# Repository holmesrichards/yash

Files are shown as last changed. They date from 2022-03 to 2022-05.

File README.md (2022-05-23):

# YASH

This is a Kosmo format version of René Schmitz's [YASH](https://www.schmitzbits.de/sah.html) sample and hold synth module.

The circuit is pretty much as Schmitz designed it. The only significant changes are the addition of an output jack for the clock signal, an attenuator for the input signal, and a switch to bypass the capacitor on the clock input. The latter turns the module from a sample and hold into a track and hold: applying a gate to the clock input causes the output to track the input voltage, and then when the gate turns off the last output voltage is held until the next gate.

## Current draw
11.3 mA +12 V, 4.0 mA -12 V

## Photos

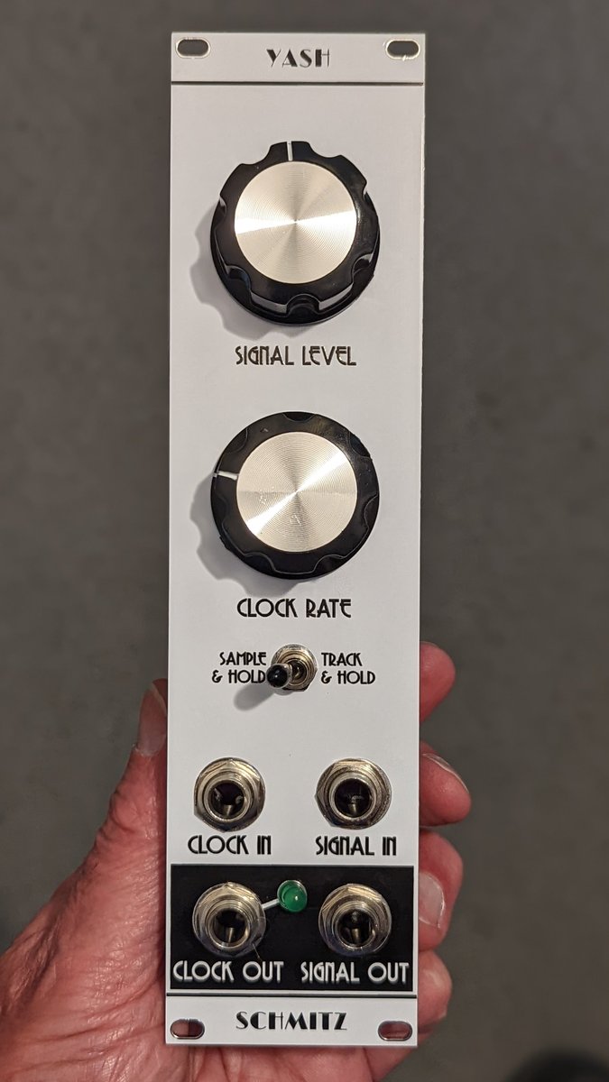
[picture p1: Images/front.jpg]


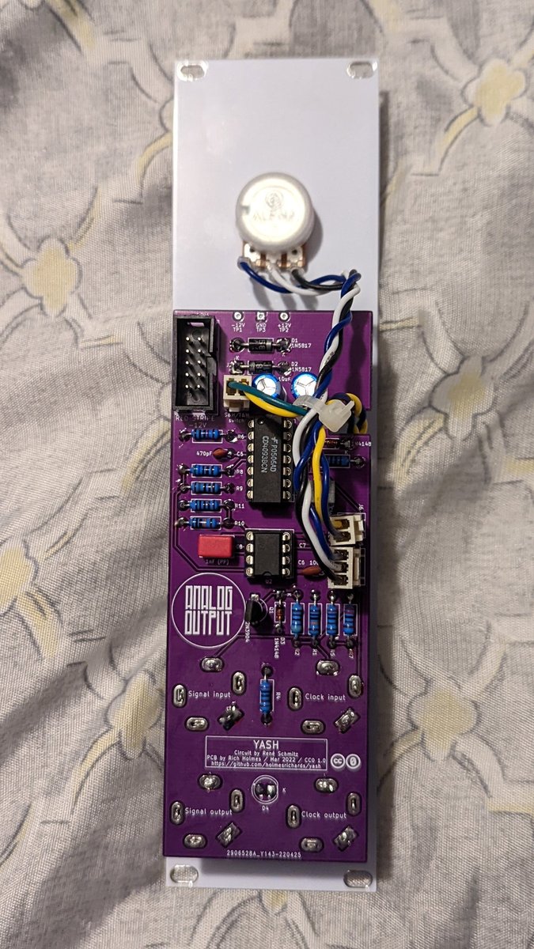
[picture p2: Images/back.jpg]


## Documentation

* [Schematic](Docs/yash.pdf)
* PCB layout: [front](Docs/yash_layout_front.pdf), [back](Docs/yash_layout_back.pdf)
* [BOM](Docs/yash_bom.md)
* [Build notes](Docs/build.md)
* [Blog post](https://analogoutputblog.wordpress.com/2022/05/06/yet-another-sample-and-hold/)

## GitHub repository

* [https://github.com/holmesrichards/yash](https://github.com/holmesrichards/yash)

## Submodules

This repo uses submodules aoKicad and Kosmo_panel, which provide needed libaries for KiCad. To clone:

```
git clone git@github.com:holmesrichards/yash.git
git submodule init
git submodule update
```

Alternatively do

```
git clone --recurse-submodules git@github.com:holmesrichards/yash.git
```

Or if you download the repository as a zip file, you must also click on the "aoKicad" and "Kosmo\_panel" links on the GitHub page (they'll have "@ something" after them) and download them as separate zip files which you can unzip into this repo's aoKicad and Kosmo\_panel directories.

If desired, copy the files from aoKicad and Kosmo\_panel to wherever you prefer (your KiCad user library directory, for instance, if you have one). Then in KiCad, go into Edit Symbols and add symbol libraries 

```
aoKicad/ao_symbols
Kosmo_panel/Kosmo
```
and go into Edit Footprints and add footprint libraries 
```
aoKicad/ao_tht
Kosmo_panel/Kosmo_panel.
```

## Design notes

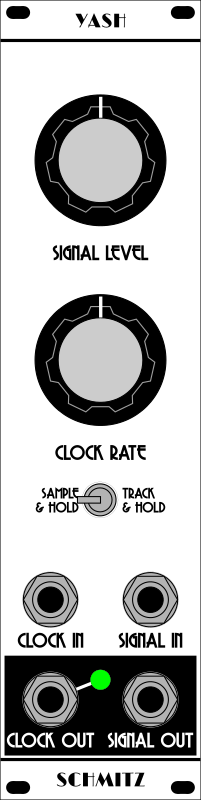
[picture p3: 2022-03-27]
Images/yash_panel.png

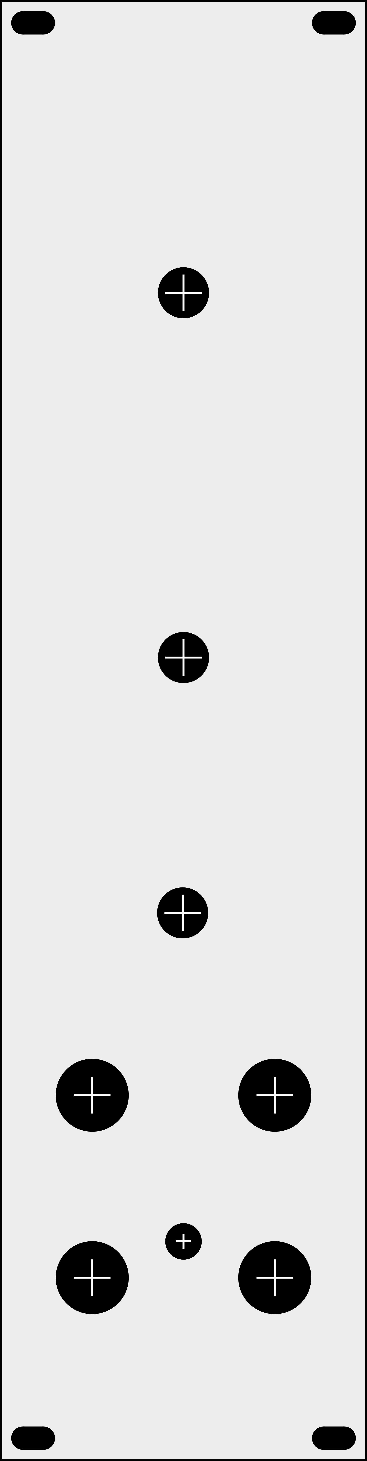
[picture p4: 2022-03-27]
Images/yash_panel_holes.png

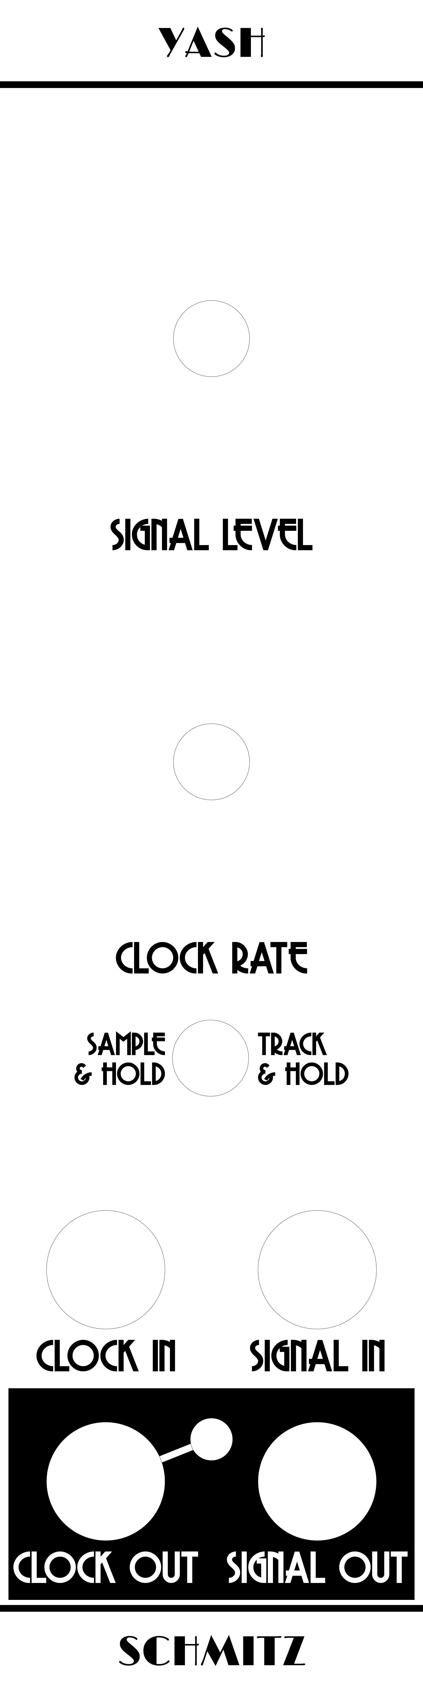
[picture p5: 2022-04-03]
Images/yash_panel_art.png

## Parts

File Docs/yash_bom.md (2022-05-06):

# yash.kicad_sch BOM

Fri 06 May 2022 05:41:29 PM EDT

Generated from schematic by Eeschema 6.0.4-6f826c9f35~116~ubuntu20.04.1

**Component Count:** 41

| Refs | Qty | Component | Description | Vendor | SKU |
| ----- | --- | ---- | --- | ---- | ---- |
| C1 | 1 | 1nF (PP) | Polypropylene capacitor | DigiKey | FKP2G011001D00HSSD |
| C2 | 1 | 470pF | Ceramic capacitor, 2.5 mm pitch | Tayda |  |
| C3 | 1 | 470nF | Polyester capacitor | Tayda | A-568 |
| C4, C6, C7 | 3 | 100nF | Ceramic capacitor, 2.5 mm pitch | Tayda | A-553 |
| C5, C8 | 2 | 10uF | Electrolytic capacitor, 2.5 mm pitch | Tayda | A-4349 |
| D1 | 1 | LED_green | Light emitting diode | Tayda | A-1553 |
| D2, D3 | 2 | 1N4148 | Standard switching diode, DO-35 | Tayda | A-157 |
| D5, D6 | 2 | 1N5817 | Schottky Barrier Rectifier Diode, DO-41 | Tayda | A-159 |
| J1, J2, J4 | 3 | AudioJack2 | 1/4" audio jack, vertical | Tayda | A-1121 |
| J3 | 1 | AudioJack2_SwitchT | 1/4" audio jack, vertical, switched | Tayda | A-1121 |
| J5 | 1 | 3_pin_Molex_header | KK254 Molex header | Tayda | A-805 |
| J6 | 1 | 3_pin_Molex_connector | KK254 Molex connector | Tayda | A-827 |
| J7, J10 | 2 | 2_pin_Molex_header | KK254 Molex header | Tayda | A-804 |
| J8, J11 | 2 | 2_pin_Molex_connector | KK254 Molex connector | Tayda | A-826 |
| J9 | 1 | Synth_power_2x5 | Pin header 2.54 mm 2x5 | Tayda | A-2939 |
| Q1 | 1 | 2N3904 | Small Signal NPN Transistor, TO-92 | Tayda | A-111 |
| R1 | 1 | 1k | 1/4 watt resistor, metal film | Tayda |  |
| R2, R8 | 2 | 100k | 1/4 watt resistor, metal film | Tayda |  |
| R3 | 1 | RL* | 1/4 watt resistor, metal film | Tayda |  |
| R4 | 1 | 5.6k | 1/4 watt resistor, metal film | Tayda |  |
| R5 | 1 | 4.7k | 1/4 watt resistor, metal film | Tayda |  |
| R6 | 1 | 10k | 1/4 watt resistor, metal film | Tayda |  |
| R7 | 1 | 1.8k | 1/4 watt resistor, metal film | Tayda |  |
| R9 | 1 | 2.7k | 1/4 watt resistor, metal film | Tayda |  |
| R10, R12 | 2 | 2.2k | 1/4 watt resistor, metal film | Tayda |  |
| RV1 | 1 | 100k | Linear potentiometer, panel mount | Tayda | A-1984 |
| RV2 | 1 | 1M | Linear potentiometer, panel mount | Tayda | A-1658 |
| SW1 | 1 | SW_SPDT | SPDT or DPDT toggle switch | Tayda | A-3186 |
| U1 | 1 | LF398 | Monolithic sample-and-hold | Digi-Key | LF398AN/NOPB-ND |
| U2 | 1 | 4093 | Quad 2-Input NAND Schmitt Trigger, DIP-14 | Tayda | A-554 |
| | 1 | | 8 pin DIP socket | Tayda | A-001 |
| | 1 | | 14 pin DIP socket | Tayda | A-004 |
| | 2 | | knobs | | |

\* Use value for suitable LED brightness, I used 2k with the BOM LED

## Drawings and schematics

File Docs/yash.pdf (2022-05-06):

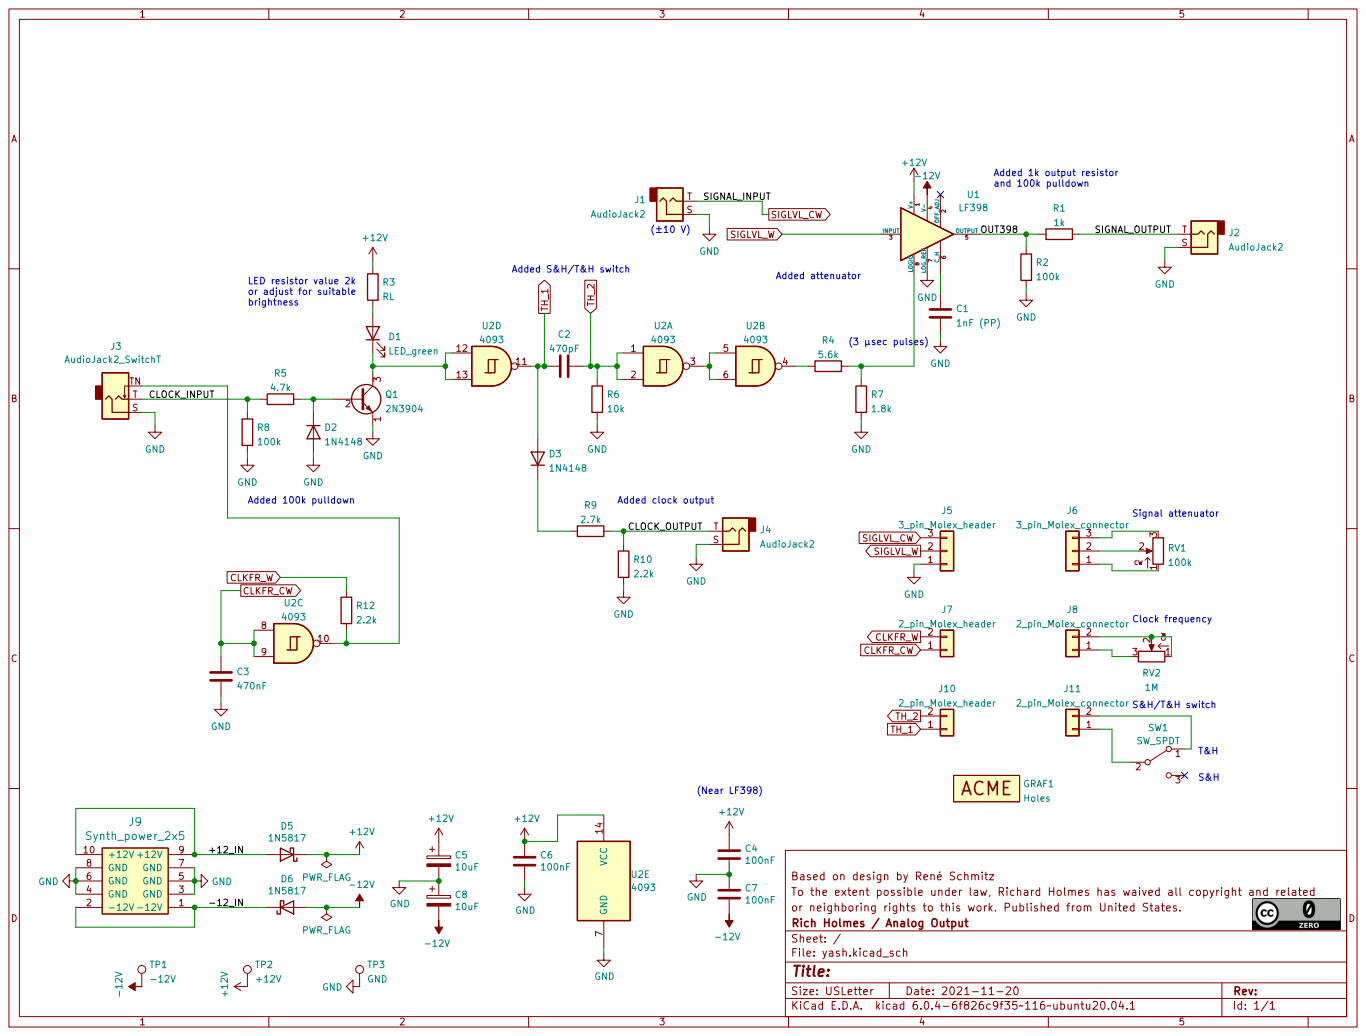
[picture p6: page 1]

Added attenuator LED resistor value 2k or adjust for suitable

or neighboring rights to this work. Published from United States.
File: yash.kicad_sch Sheet: / Rich Holmes / Analog Output

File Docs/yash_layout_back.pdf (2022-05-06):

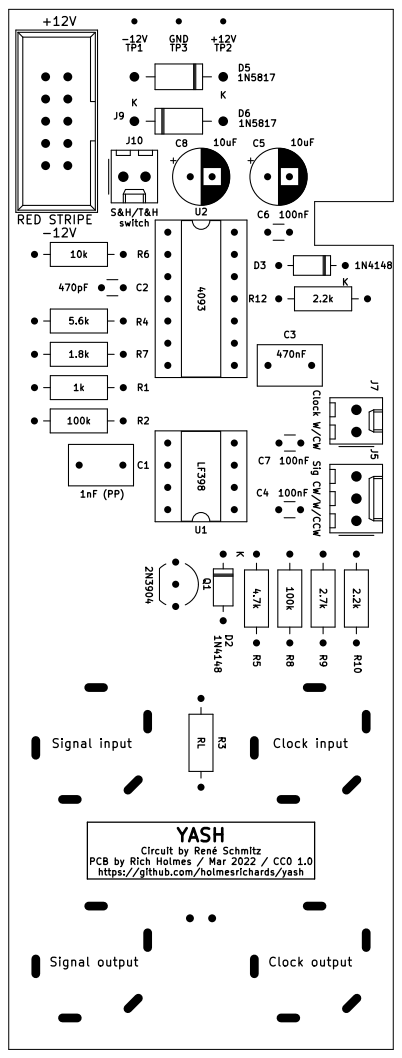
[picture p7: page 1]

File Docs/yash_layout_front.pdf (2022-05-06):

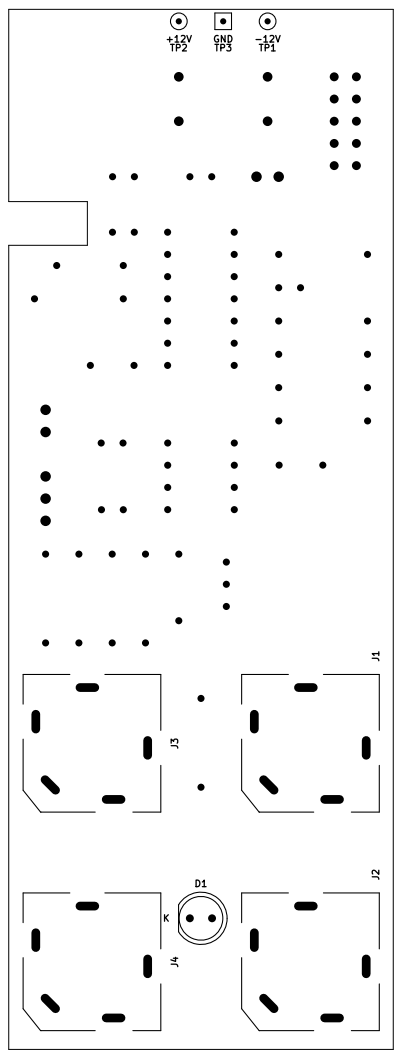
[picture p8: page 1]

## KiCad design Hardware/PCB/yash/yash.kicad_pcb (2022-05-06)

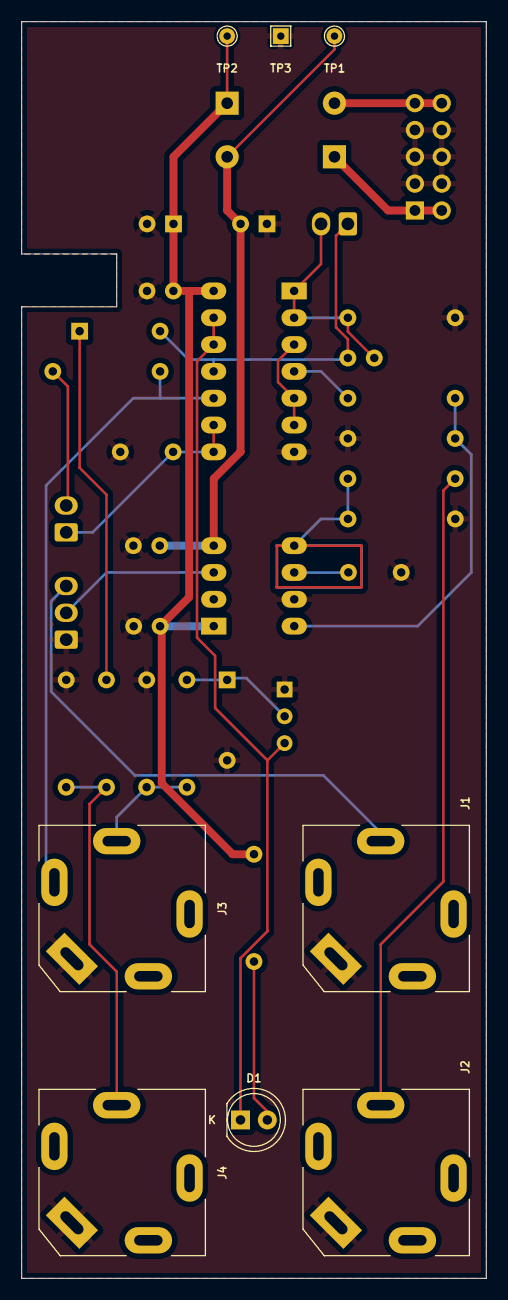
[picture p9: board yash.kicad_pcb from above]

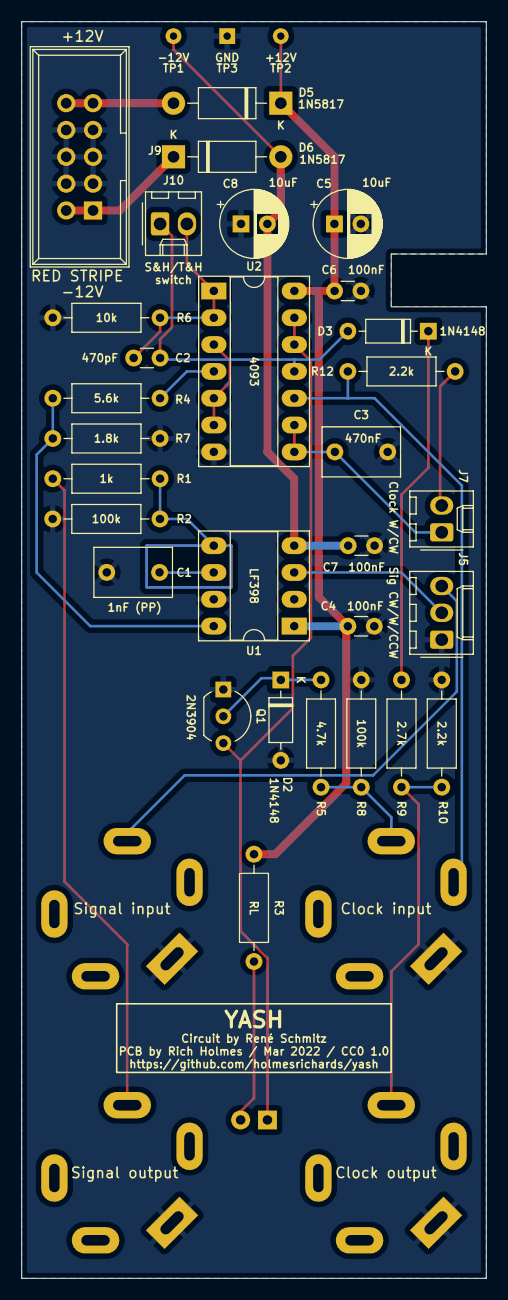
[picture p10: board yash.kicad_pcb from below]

Board: 2 copper layers, 44.0 x 119.0 mm, 39 parts (30 on the bottom side), 24 nets.

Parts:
C1: 1nF (PP); C_Rect_L7.2mm_W4.5mm_P5.00mm_FKS2_FKP2_MKS2_MKP2
C2: 470pF; C_Disc_D3.0mm_W1.6mm_P2.50mm
C3: 470nF; C_Rect_L7.2mm_W4.5mm_P5.00mm_FKS2_FKP2_MKS2_MKP2
C4, C6, C7: 100nF; C_Disc_D3.0mm_W1.6mm_P2.50mm
C5, C8: 10uF; CP_Radial_D6.3mm_P2.50mm
D1: LED_green; LED_D5.0mm
D2, D3: 1N4148; D_DO-35_SOD27_P7.62mm_Horizontal
D5, D6: 1N5817; D_DO-41_SOD81_P10.16mm_Horizontal
GRAF1: Holes; yash_panel_holes
J1, J2, J4: AudioJack2; Jack_6.35mm_PJ_629HAN_slots
J3: AudioJack2_SwitchT; Jack_6.35mm_PJ_629HAN_slots
J5: 3_pin_Molex_header; Molex_KK-254_AE-6410-03A_1x03_P2.54mm_Vertical
J7, J10: 2_pin_Molex_header; Molex_KK-254_AE-6410-02A_1x02_P2.54mm_Vertical
J9: Synth_power_2x5; Power_Header
Q1: 2N3904; TO-92_Inline_Wide
R1: 1k; R_Axial_DIN0207_L6.3mm_D2.5mm_P10.16mm_Horizontal
R2, R8: 100k; R_Axial_DIN0207_L6.3mm_D2.5mm_P10.16mm_Horizontal
R3: RL; R_Axial_DIN0207_L6.3mm_D2.5mm_P10.16mm_Horizontal
R4: 5.6k; R_Axial_DIN0207_L6.3mm_D2.5mm_P10.16mm_Horizontal
R5: 4.7k; R_Axial_DIN0207_L6.3mm_D2.5mm_P10.16mm_Horizontal
R6: 10k; R_Axial_DIN0207_L6.3mm_D2.5mm_P10.16mm_Horizontal
R7: 1.8k; R_Axial_DIN0207_L6.3mm_D2.5mm_P10.16mm_Horizontal
R9: 2.7k; R_Axial_DIN0207_L6.3mm_D2.5mm_P10.16mm_Horizontal
R10, R12: 2.2k; R_Axial_DIN0207_L6.3mm_D2.5mm_P10.16mm_Horizontal
TP1: -12V; TestPoint_THTPad_D1.5mm_Drill0.7mm
TP2: +12V; TestPoint_THTPad_D1.5mm_Drill0.7mm
TP3: GND; TestPoint_THTPad_1.5x1.5mm_Drill0.7mm
U1: LF398; DIP-8_W7.62mm_Socket_LongPads
U2: 4093; DIP-14_W7.62mm_Socket_LongPads

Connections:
+12V: C4.1, C5.1, C6.1, D5.1 (K), R3.1, TP2.1, U1.1 (V+), U2.14 (VCC)
-12V: C7.2, C8.2, D6.2 (A), TP1.1, U1.4 (V-)
/+12_IN: D5.2 (A), J9.9 (+12V), J9.10 (+12V)
/-12_IN: D6.1 (K), J9.1 (-12V), J9.2 (-12V)
/CLOCK_INPUT: J3.T, R5.1, R8.1
/CLOCK_OUTPUT: J4.T, R9.2, R10.1
/OUT398: R1.1, R2.1, U1.5 (OUTPUT)
/SIGNAL_OUTPUT: J2.T, R1.2
CLKFR_CW: C3.1, J7.1, U2.8, U2.9
CLKFR_W: J7.2, R12.1
GND: C1.2, C3.2, C4.2, C5.2, C6.2, C7.1, C8.1, D2.2 (A), J1.S, J2.S, J3.S, J4.S, J5.1, J9.3 (GND), J9.4 (GND), J9.5 (GND), J9.6 (GND), J9.7 (GND), J9.8 (GND), Q1.1 (E), R2.2, R6.2, R7.2, R8.2, R10.2, TP3.1, U1.7 (LOG_REF), U2.7 (GND)
unnamed: C1.1, U1.6 (C_H)
unnamed: D1.1 (K), Q1.3 (C), U2.12, U2.13
unnamed: D1.2 (A), R3.2
unnamed: D2.1 (K), Q1.2 (B), R5.2
unnamed: D3.1 (K), R9.1
unnamed: J3.TN, R12.2, U2.10
unnamed: R4.1, U2.4
unnamed: R4.2, R7.1, U1.8 (LOGIC)
unnamed: U2.3, U2.5, U2.6
SIGLVL_CW: J1.T, J5.3
SIGLVL_W: J5.2, U1.3 (INPUT)
TH_1: C2.1, D3.2 (A), J10.1, U2.11
TH_2: C2.2, J10.2, R6.1, U2.1, U2.2

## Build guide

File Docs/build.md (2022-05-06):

# YASH build notes

## ERRATA

In the first run of the PCB, the pins for the clock frequency Molex header are mislabeled. The label should say "Clock W/CW", not "Clock W/CCW".

Also in the first run, the LED footprint silkscreen is on the wrong side of the PCB. The LED should of course be mounted on the same side as the jacks, opposite the other components.

These were corrected after the first run.

# Build

There's nothing exotic about this build. Proceed as usual.

Pins 1 and 2 (counterclockwise and wiper pins as viewed from front) of the Clock Rate pot should be connected together, and pins 2 and 3 should be wired to the PCB via Molex connectors or soldered directly. All three pins of the Signal Level pot should be wired to the PCB. Mount the S&H/T&H switch horizontally, and then the left and center pins (again as viewed from front) should be wired to the PCB. See labels on the PCB indicating which pin goes to which point (noting Erratum above).

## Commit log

2022-03-27 Initial version
    [yash.kicad_pcb, yash.kicad_sch]
2022-04-03 README, panel and PCB tweaks
    [yash.kicad_pcb, yash_panel.kicad_pcb, yash_panel.kicad_sch]
2022-04-24 Redo guard ring as redundant tracks
    [yash.kicad_pcb, yash.kicad_sch]
2022-05-06 CW not CCW, put LED on correct side of PCB
    [yash.kicad_pcb, yash.kicad_sch]
2022-05-06 Post fab updates
    [yash-CmtUser.gbr, yash-CuBottom.gbl, yash-CuTop.gtl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]
2022-05-23 Current draw

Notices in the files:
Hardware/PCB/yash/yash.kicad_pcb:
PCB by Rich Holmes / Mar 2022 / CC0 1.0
